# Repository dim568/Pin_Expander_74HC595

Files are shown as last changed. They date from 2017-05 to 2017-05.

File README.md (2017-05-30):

# Pin_Expander_74HC595
SPI Expander Board On 74HC595

KiCAD 4.0.4
PCB Design 03.05.17

PCB Have SilkScreen numeration error
- 23 -> 16
- 22 -> 17
- 21 -> 18
- 20 -> 19
- 19 -> 20
- 18 -> 21
- 17 -> 22
- 16 -> 23
- 15 -> 08
- 14 -> 09
- 13 -> 10
- 12 -> 11
- 11 -> 12
- 10 -> 13
- 09 -> 14
- 08 -> 15
- 07 -> 00
- 06 -> 01
- 05 -> 02
- 04 -> 03
- 03 -> 04
- 02 -> 05
- 01 -> 06
- 00 -> 07

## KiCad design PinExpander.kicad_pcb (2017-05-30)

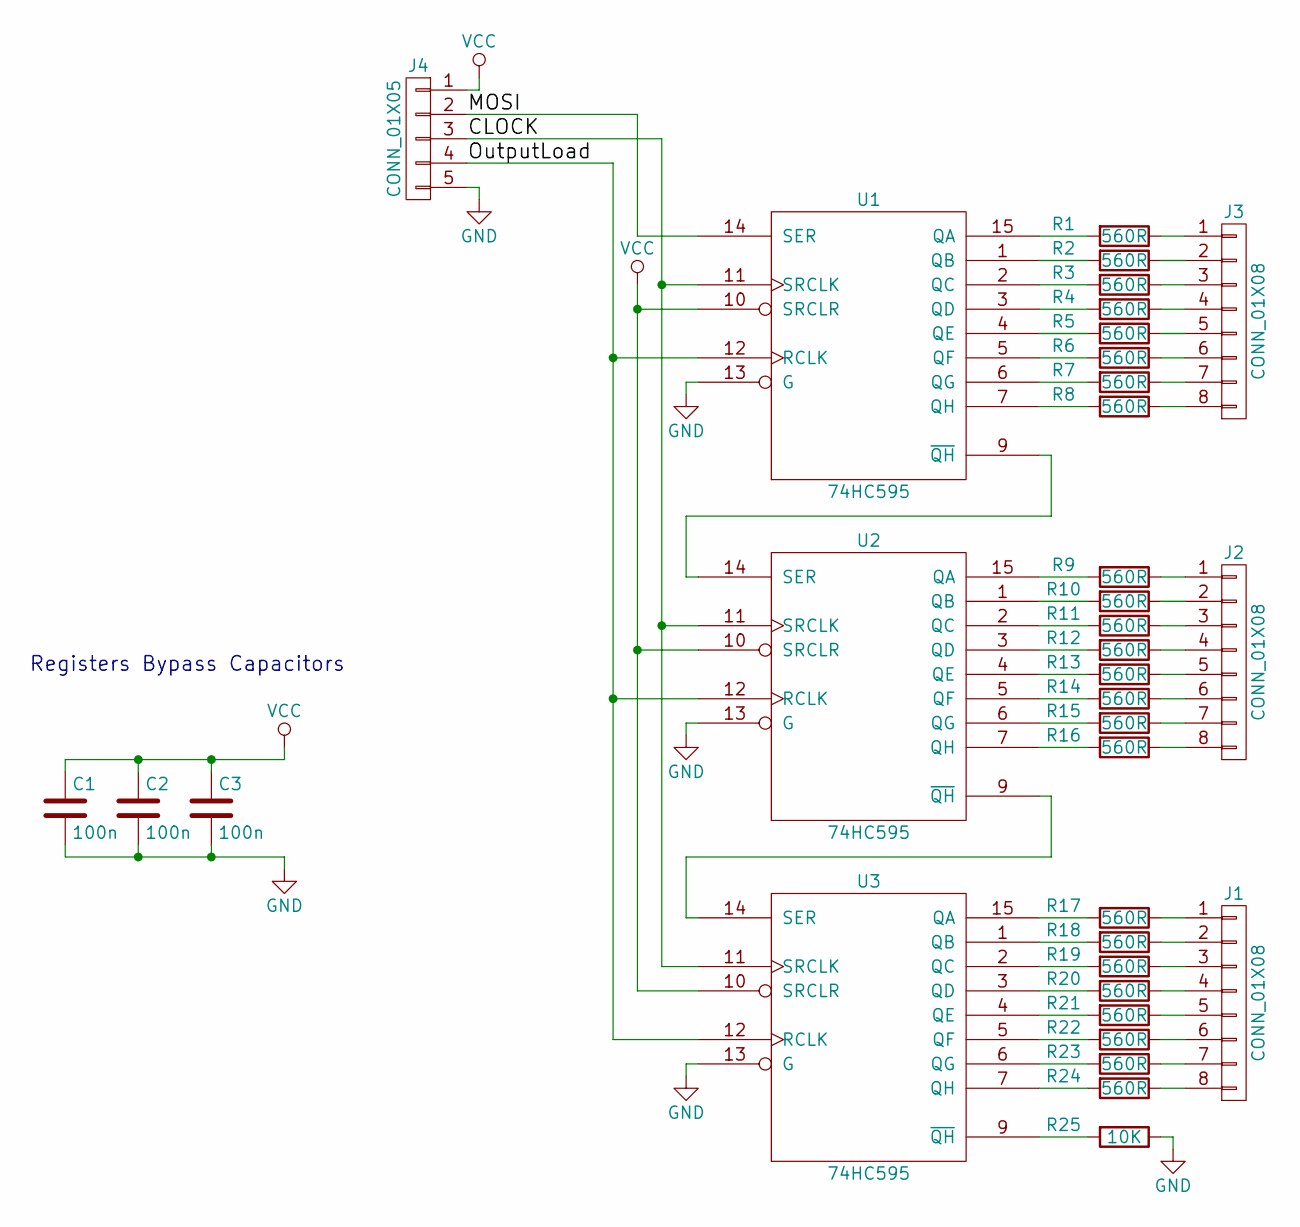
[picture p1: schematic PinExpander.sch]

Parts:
C1, C2, C3: 100n; C_1206_HandSoldering
J1, J2, J3: CONN_01X08; Pin_Header_Straight_1x08_Pitch2.54mm
J4: CONN_01X05; Pin_Header_Straight_1x05_Pitch2.54mm
R1, R2, R3, R4, R5, R6, R7, R8, R9, R10, R11, R12, R13, R14, R15, R16, R17, R18, R19, R20, R21, R22, R23, R24: 560R; R_1206_HandSoldering
R25: 10K; R_1206_HandSoldering
U1, U2, U3: 74HC595; SOIC-16_3.9x9.9mm_Pitch1.27mm

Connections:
/CLOCK: J4.3, U1.11 (SRCLK), U2.11 (SRCLK), U3.11 (SRCLK)
/MOSI: J4.2, U1.14 (SER)
/OutputLoad: J4.4, U1.12 (RCLK), U2.12 (RCLK), U3.12 (RCLK)
GND: C1.2, C2.2, C3.2, J4.5, R25.1, U1.8 (GND), U1.13 (G), U2.8 (GND), U2.13 (G), U3.8 (GND), U3.13 (G)
unnamed: J1.1, R17.1
unnamed: J1.2, R18.1
unnamed: J1.3, R19.1
unnamed: J1.4, R20.1
unnamed: J1.5, R21.1
unnamed: J1.6, R22.1
unnamed: J1.7, R23.1
unnamed: J1.8, R24.1
unnamed: J2.1, R9.1
unnamed: J2.2, R10.1
unnamed: J2.3, R11.1
unnamed: J2.4, R12.1
unnamed: J2.5, R13.1
unnamed: J2.6, R14.1
unnamed: J2.7, R15.1
unnamed: J2.8, R16.1
unnamed: J3.1, R1.1
unnamed: J3.2, R2.1
unnamed: J3.3, R3.1
unnamed: J3.4, R4.1
unnamed: J3.5, R5.1
unnamed: J3.6, R6.1
unnamed: J3.7, R7.1
unnamed: J3.8, R8.1
unnamed: R1.2, U1.15 (QA)
unnamed: R2.2, U1.1 (QB)
unnamed: R3.2, U1.2 (QC)
unnamed: R4.2, U1.3 (QD)
unnamed: R5.2, U1.4 (QE)
unnamed: R6.2, U1.5 (QF)
unnamed: R7.2, U1.6 (QG)
unnamed: R8.2, U1.7 (QH)
unnamed: R9.2, U2.15 (QA)
unnamed: R10.2, U2.1 (QB)
unnamed: R11.2, U2.2 (QC)
unnamed: R12.2, U2.3 (QD)
unnamed: R13.2, U2.4 (QE)
unnamed: R14.2, U2.5 (QF)
unnamed: R15.2, U2.6 (QG)
unnamed: R16.2, U2.7 (QH)
unnamed: R17.2, U3.15 (QA)
unnamed: R18.2, U3.1 (QB)
unnamed: R19.2, U3.2 (QC)
unnamed: R20.2, U3.3 (QD)
unnamed: R21.2, U3.4 (QE)
unnamed: R22.2, U3.5 (QF)
unnamed: R23.2, U3.6 (QG)
unnamed: R24.2, U3.7 (QH)
unnamed: R25.2, U3.9 (~QH)
unnamed: U1.9 (~QH), U2.14 (SER)
unnamed: U2.9 (~QH), U3.14 (SER)
VCC: C1.1, C2.1, C3.1, J4.1, U1.10 (SRCLR), U1.16 (VCC), U2.10 (SRCLR), U2.16 (VCC), U3.10 (SRCLR), U3.16 (VCC)

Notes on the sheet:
Registers Bypass Capacitors

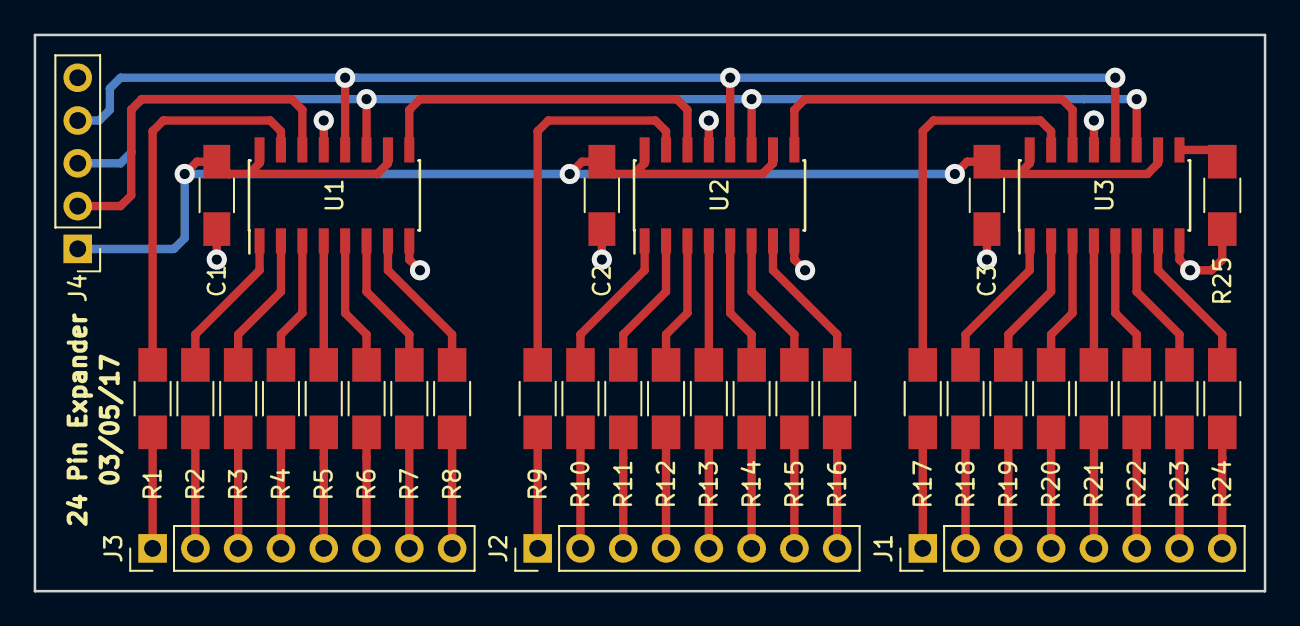
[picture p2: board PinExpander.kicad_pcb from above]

Board: 2 copper layers, 73.0 x 33.0 mm, 35 parts (0 on the bottom side), 56 nets.
